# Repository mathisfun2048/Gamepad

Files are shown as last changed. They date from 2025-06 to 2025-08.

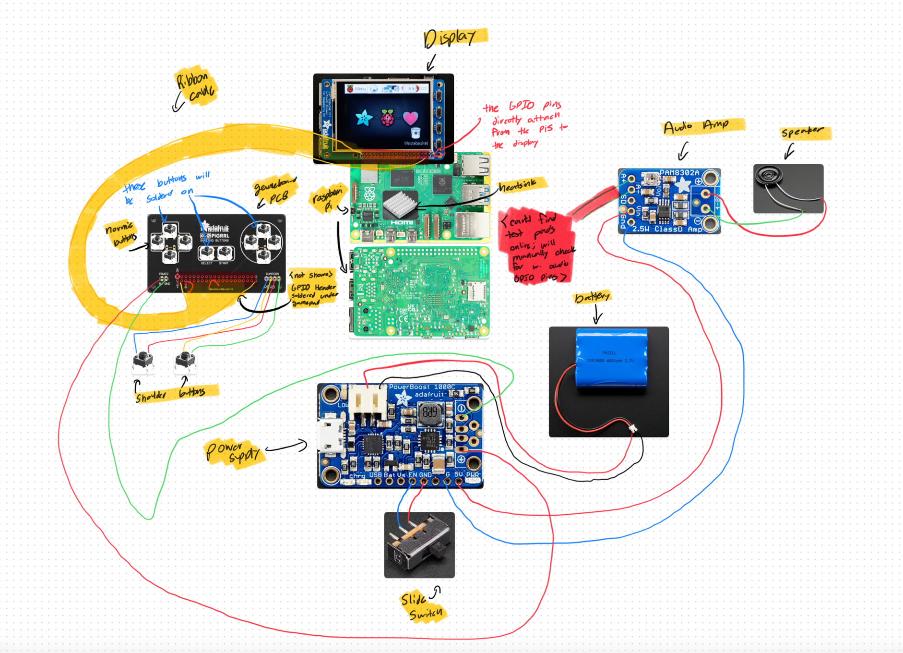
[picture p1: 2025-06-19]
Wiring/Screenshot 2025-06-19 at 6.52.05 AM.png

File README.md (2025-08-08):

# Gamepad


## Description and Exigence
Hallo! This is my second attempt at hardware design! This time, instead of focusing on a PCB, I wanted to investigate how multiple different parts can come together to create a product. The goal of this project is to create a functional gameboy-esq device that I can play games on! Initially this project was meant to fit inside of an altoids tin, but that was above my skill grade, so I downgraded to a slighly clunkier console. 

I have always enjoyed playing video games but never really considered how the hardware was created. So, this project hit 2 birds with 1 stone: I get a super cool gaming console to add to my collection and I get to learn about hardware >:) 
This project helped me get a glimse and greater appreciation of how hard hardware desgining and moreso planning. However, I picked up some cool skills which was really fun. 

A goal I had for this project specficially was to learn how to CAD using code, which I was able to do using a python script! I can't wait to see how it looks printed out irl. I have always been into coding and its been great seeing a way to directly merge my interest for talking with computers with creating something physical. 

Okay enough yap. If you want more stream of consciousness, look at my journal ;)

## PICTURES

### Schematic

Screenshot 2025-06-30 at 4 40 49 AM

Screenshot 2025-06-23 at 3 18 57 PM

### PCB 

Screenshot 2025-06-30 at 4 41 06 AM

Screenshot 2025-06-23 at 3 19 37 PM

### project as a whole

Everything Together

Top View

## Firmware
So tldr I don't know how to code games (yet!) so I will be utalizing RetroPi. It is not included in this repo because 1) github was being finicky about pushing it from my desktop folder and 2) its avalible online readilly 

## BOM

Here's everything you need if you want to build this too! (also includes sweat and tears... forgot to include that in the table)

Also, you might be wonderign why everything is either from Microcenter or Adafruit and not cheaper alternatives like AliExpress. The short answer is my parents won't allow me to purchase stuff from aliexpress. However, if my cost goes above the alloted $150 with future edits or anything, I will be more than happy to pay out of pocket. If this project gets downgraded to 4 points, I'd also be willing to pay out of pocket because this is honestly pretty cool and I want to see it in person. I never got a handheld video game console as a kid and I'm excited that I'll be able to make one now :)

| Item | Quantity | Cost | Source | Link |
| --- | --- | --- | --- | --- |
| Raspberry Pi Zero 2 | 1 | 14.99 | Microcenter | [Link](https://www.microcenter.com/product/643085/raspberry-pi-zero-2-w) |
| GPIO header | 1 | 5.99 | Microcenter | [Link](https://www.microcenter.com/product/480889/schmartboard-inc-schmartboard-inc-2-x-20-male-headers-qty-5) |
| 2.2" Display | 1 | 24.95 | Adafruit | [Link](https://www.adafruit.com/product/2315) |
| Custom PCB | 1 | $9 + shipping | JCL PCB | |
| PowerBoost 1000c | 1 | 19.99 | Microcenter | [Link](https://www.microcenter.com/product/474415/adafruit-industries-powerboost-1000-charger-rechargeable-5v-lipo-usb-boost-@-1a) |
| 2500 mAh Battery | 1 | 14.99 | Adafruit | [Link](https://www.microcenter.com/product/454401/adafruit-industries-lithium-ion-polymer-battery-37v-2500mah) |
| stacking header | 1 | 2.95 | Adafruit | [Link](https://www.adafruit.com/product/1979?srsltid=AfmBOoqbo1ndLmYMVLTt_bqD4Yhi48SgEFRf9jc0nGi86ePSABa_MOBi) |
| Slide Switch | 1 | 0.95 | Adafruit | [Link](https://www.adafruit.com/product/805) |
| 6mm Tactile Buttons | 10 | 9.99 | Microcenter | [Link](https://www.microcenter.com/product/632688/inland-6x6mm-micro-momentary-tactile-push-button-switches-assortment-kit-10-values-180-pcs) |
| #4-40 3/8" Machine Screws | 14 | 0.00 | Myself | n/a |
| #2-56 3/8" Machine Screws | 6 | 0.00 | Myself | n/a |
| **Total** |  | **~110** | |

## Closing Remarks On Planning

This has been such a fun thing to fall into this rabbithole where I could desing this. Without Highway (shoutout Hack Club!) I would never have learned this much about hardware in such a short time; I am very grateful for this opportunity. While I do have to part now, I can't wait to build it and enter in my final remarks after I get this to work!

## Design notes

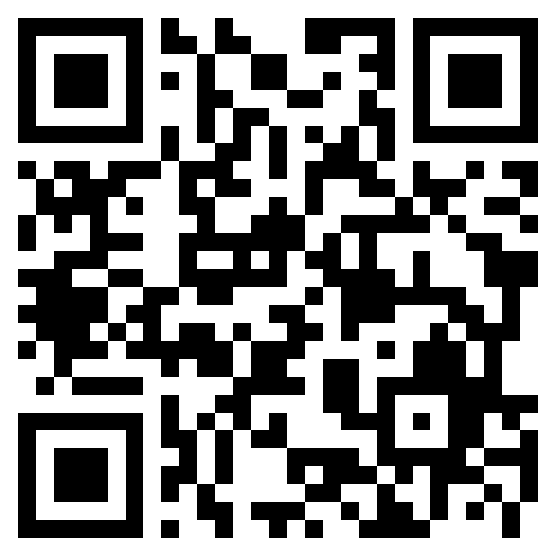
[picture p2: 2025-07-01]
Assets/Image.png

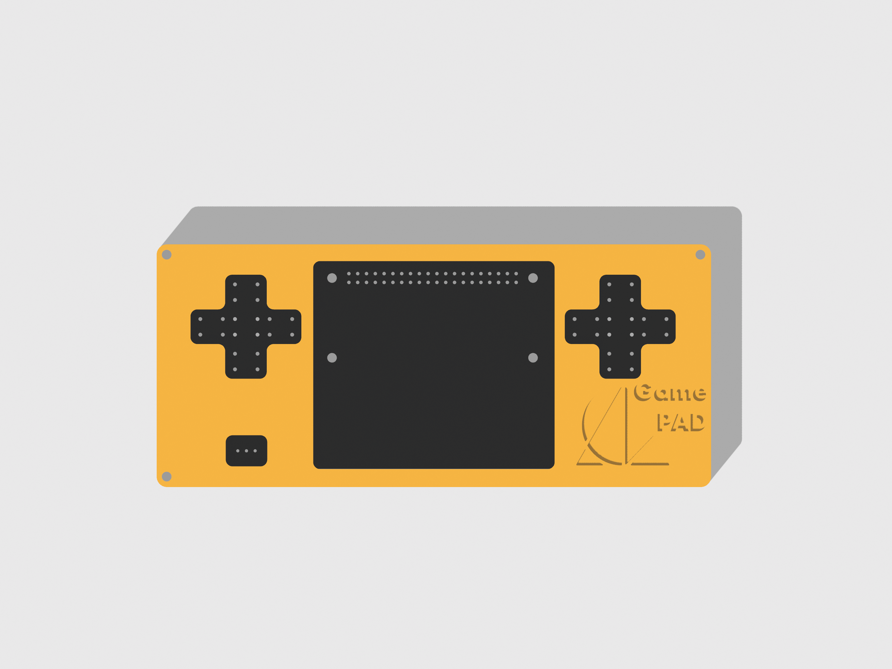
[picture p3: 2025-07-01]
Assets/Top View.png

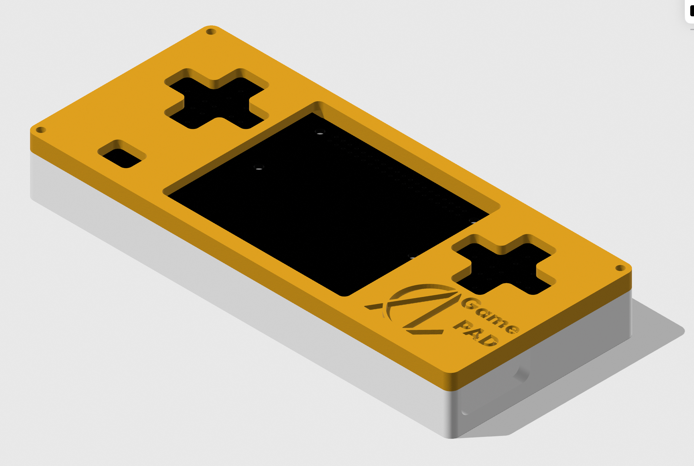
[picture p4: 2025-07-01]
Assets/Everything Together.jpeg

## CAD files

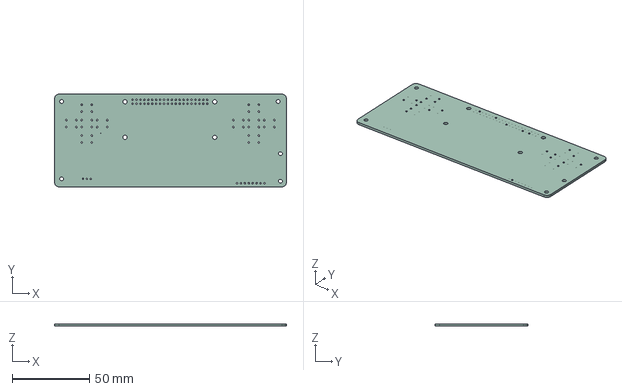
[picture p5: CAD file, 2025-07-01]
CAD/Gamepad_PCB.step
150.0 x 60.0 x 1.51 mm

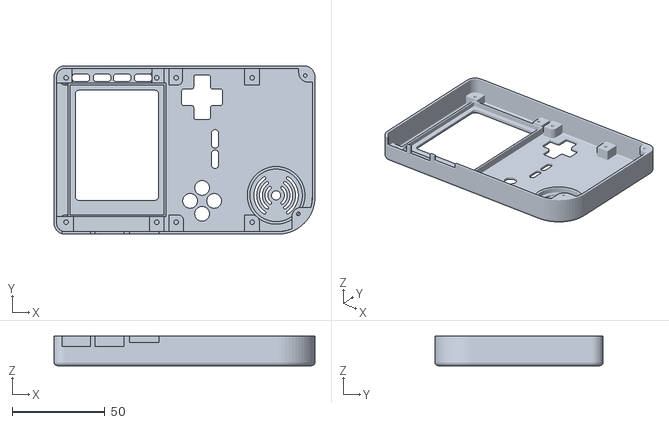
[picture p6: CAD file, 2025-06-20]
Production/top case for gamepad v2 copy.stl
141.0 x 91.0 x 16.0

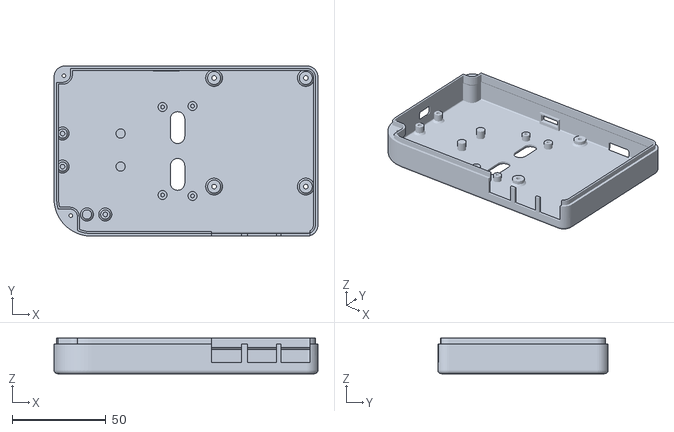
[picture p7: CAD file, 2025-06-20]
Production/bottom case for gamepad v4 copy.stl
141.0 x 91.0 x 19.0

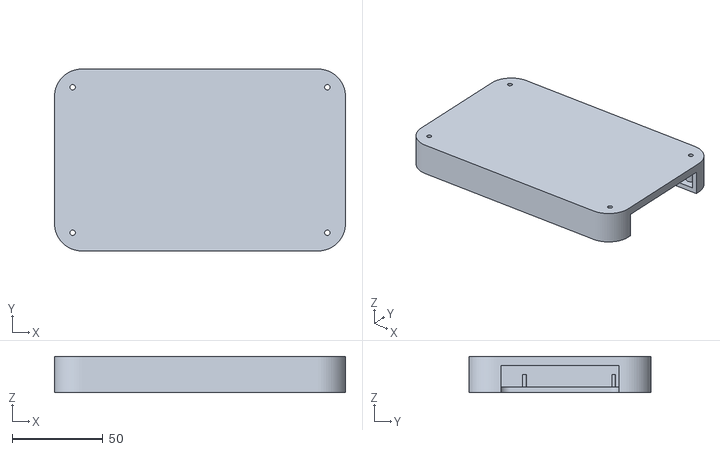
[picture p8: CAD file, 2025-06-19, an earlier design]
CAD/bottom case for gamepad v3.stl
160.0 x 100.0 x 20.0

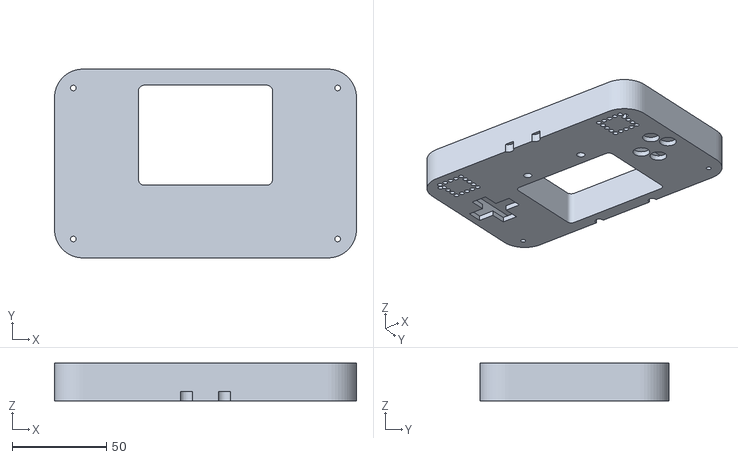
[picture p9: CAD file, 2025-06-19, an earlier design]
CAD/top case for gamepad v1.stl
160.0 x 100.0 x 20.0

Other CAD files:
CAD/bottom case for gamepad v4 STEP.step
CAD/top case for gamepad v2 STEP.step
archive from old design/bottom case for gamepad v4 STEP.step
archive from old design/top case for gamepad v2 STEP.step

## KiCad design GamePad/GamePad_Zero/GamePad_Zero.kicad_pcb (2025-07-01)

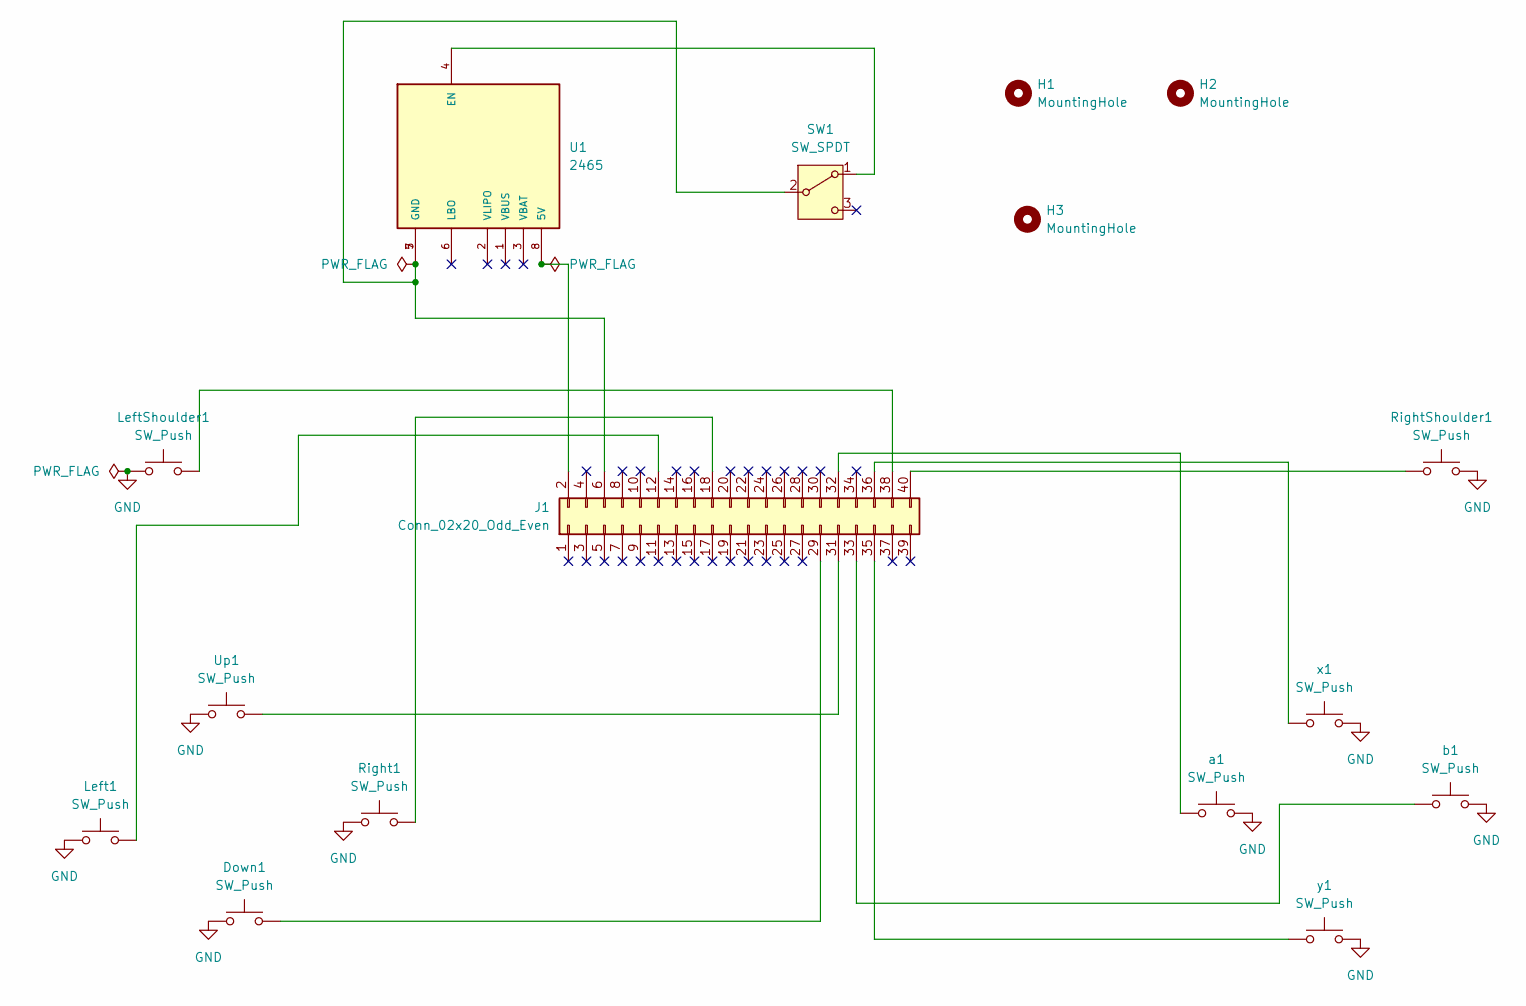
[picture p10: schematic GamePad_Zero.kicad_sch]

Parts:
Down1: SW_Push; SW_PUSH_6mm
H1, H2, H3: MountingHole; MountingHole_2.5mm
J1: Conn_02x20_Odd_Even; MODULE_SC1176
Left1: SW_Push; SW_PUSH_6mm
LeftShoulder1: SW_Push; SW_PUSH_6mm
Right1: SW_Push; SW_PUSH_6mm
RightShoulder1: SW_Push; SW_PUSH_6mm
SW1: SW_SPDT; SW_MINI-SPDT-SW
U1: 2465; MODULE_2465; PARTREV B
Up1: SW_Push; SW_PUSH_6mm
a1: SW_Push; SW_PUSH_6mm
b1: SW_Push; SW_PUSH_6mm
x1: SW_Push; SW_PUSH_6mm
y1: SW_Push; SW_PUSH_6mm

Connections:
GND: Down1.1, Left1.1, LeftShoulder1.1, Right1.1, RightShoulder1.2, Up1.1, a1.2, b1.2, x1.2, y1.2
unnamed: J1.2, U1.8 (5V)
unnamed: J1.6, SW1.2 (B), U1.5 (GND), U1.7 (GND)
unnamed: J1.12, Left1.2
unnamed: J1.18, Right1.2
unnamed: Down1.2, J1.29
unnamed: J1.31, Up1.2
unnamed: J1.32, a1.1
unnamed: J1.33, b1.1
unnamed: J1.35, y1.1
unnamed: J1.36, x1.1
unnamed: J1.38, LeftShoulder1.2
unnamed: J1.40, RightShoulder1.1
unnamed: SW1.1 (A), U1.4 (EN)

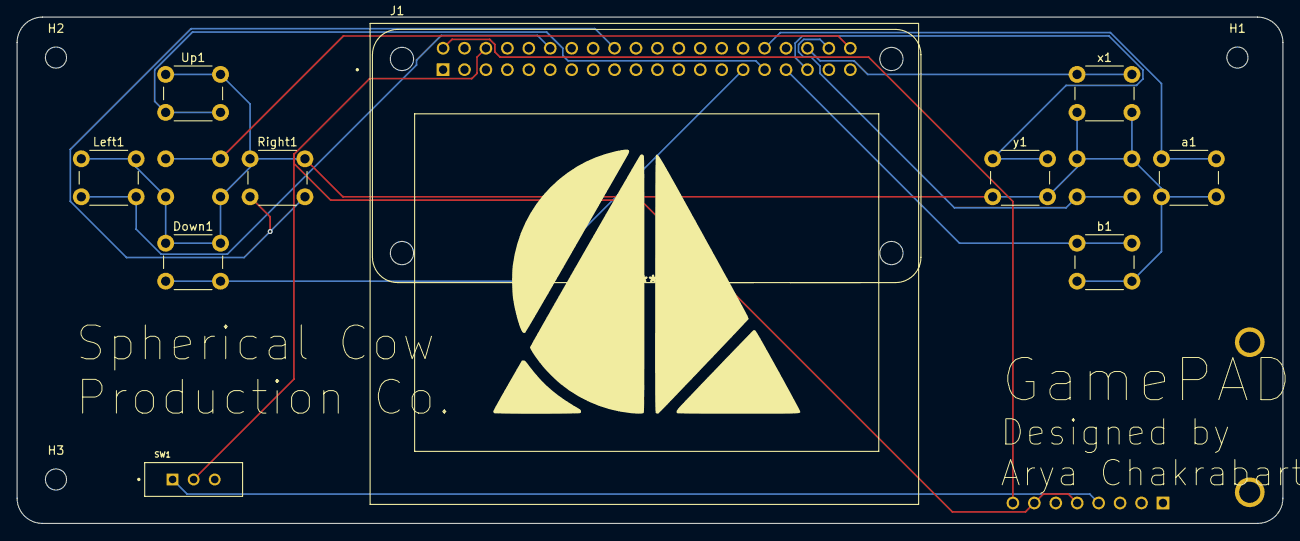
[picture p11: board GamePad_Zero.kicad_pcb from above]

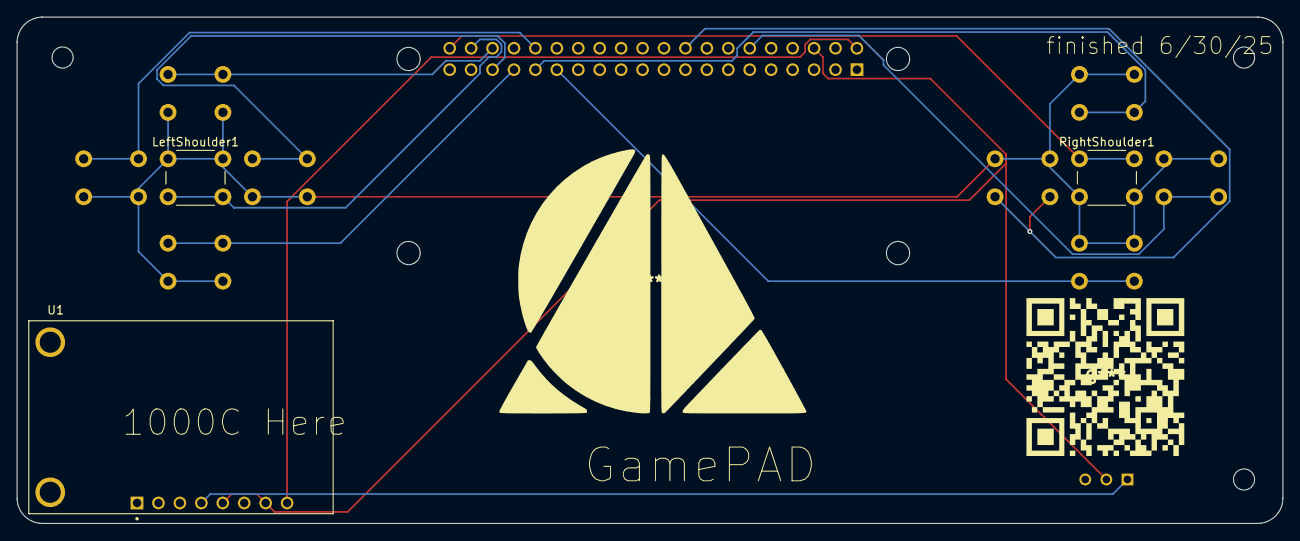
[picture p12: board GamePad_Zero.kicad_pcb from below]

Board: 2 copper layers, 150.0 x 60.0 mm, 16 parts (3 on the bottom side), 14 nets.

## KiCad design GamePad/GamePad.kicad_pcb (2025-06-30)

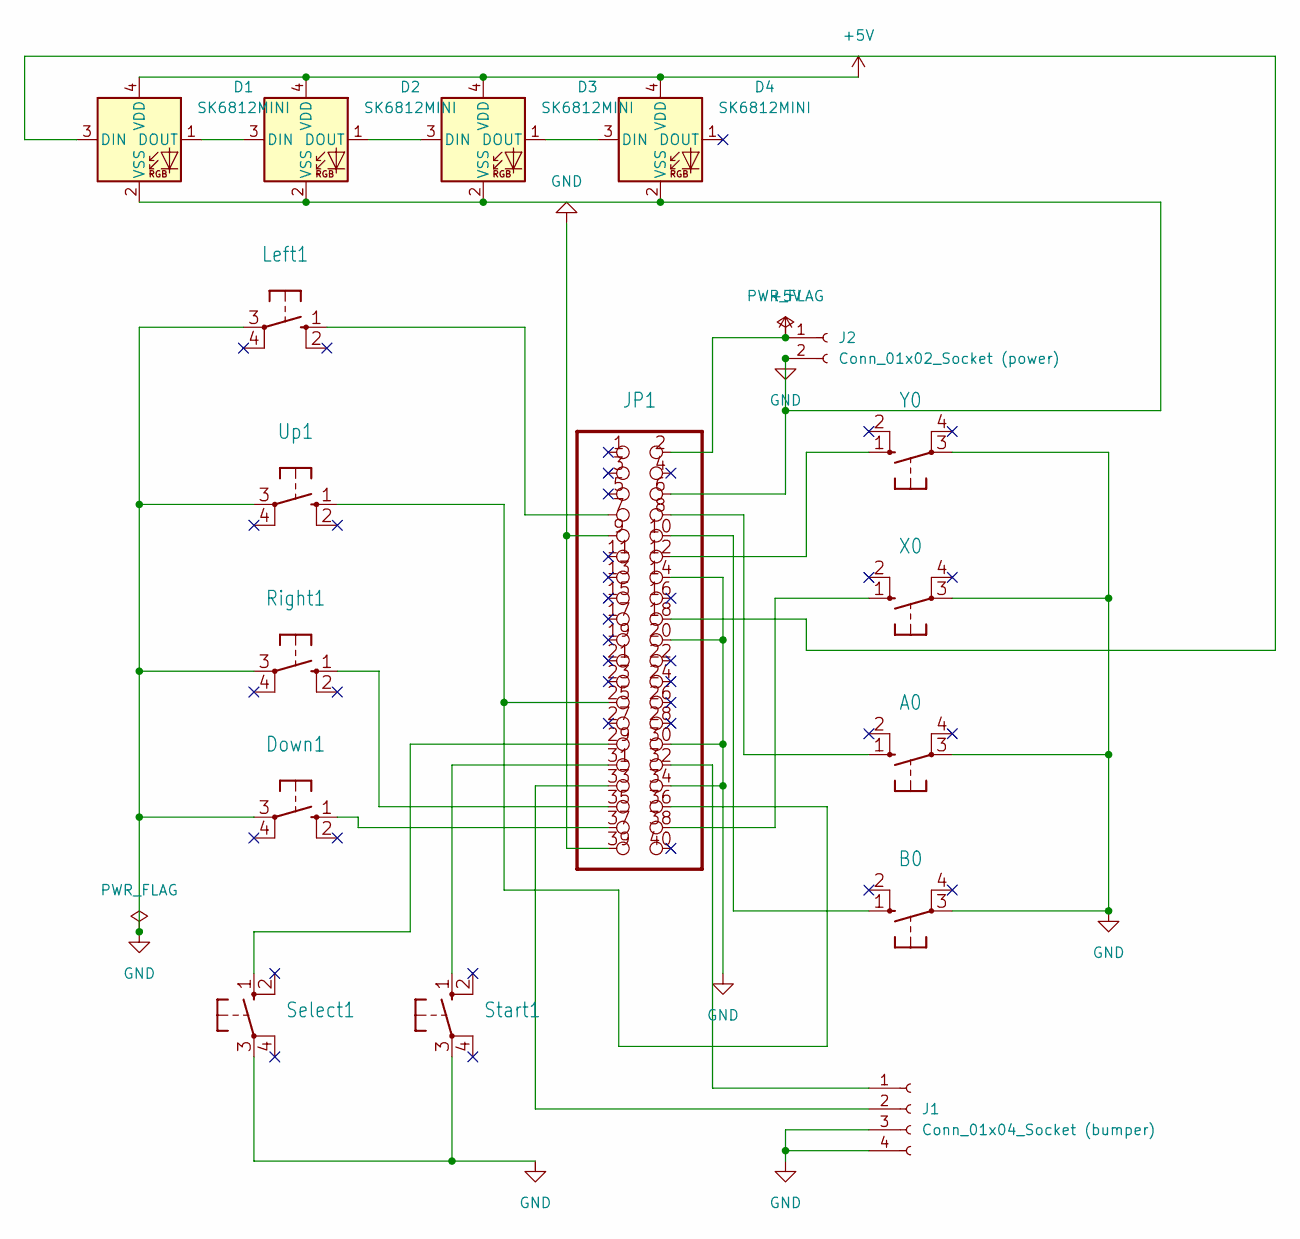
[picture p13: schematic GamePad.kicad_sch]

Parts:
A0: B3F-10XX
B0: B3F-10XX
D1, D2, D3, D4: SK6812MINI; LED_SK6812MINI_PLCC4_3.5x3.5mm_P1.75mm
Down1: B3F-10XX
J1: Conn_01x04_Socket (bumper); 1X04
J2: Conn_01x02_Socket (power); 1X02
JP1: 2X20
Left1: B3F-10XX
Right1: B3F-10XX
Select1: B3F-10XX
Start1: B3F-10XX
Up1: B3F-10XX
X0: B3F-10XX
Y0: B3F-10XX

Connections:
+5V: D1.4 (VDD), D2.4 (VDD), D3.4 (VDD), D4.4 (VDD), J2.1, JP1.2
GND: A0.3, B0.3, D1.2 (VSS), D2.2 (VSS), D3.2 (VSS), D4.2 (VSS), Down1.3, J1.3, J1.4, J2.2, JP1.6, JP1.9, JP1.14, JP1.20, JP1.30, JP1.34, JP1.39, Left1.3, Right1.3, Select1.3, Start1.3, Up1.3, X0.3, Y0.3
unnamed: A0.1 (S), JP1.8
unnamed: B0.1 (S), JP1.10
unnamed: D1.3 (DIN), JP1.18
unnamed: D1.1 (DOUT), D2.3 (DIN)
unnamed: D2.1 (DOUT), D3.3 (DIN)
unnamed: D3.1 (DOUT), D4.3 (DIN)
unnamed: Down1.1 (S), JP1.37
unnamed: J1.1, JP1.32
unnamed: J1.2, JP1.33
unnamed: JP1.7, Left1.1 (S)
unnamed: JP1.35, Right1.1 (S)
unnamed: JP1.29, Select1.1 (S)
unnamed: JP1.31, Start1.1 (S)
unnamed: JP1.25, JP1.36, Up1.1 (S)
unnamed: JP1.38, X0.1 (S)
unnamed: JP1.12, Y0.1 (S)

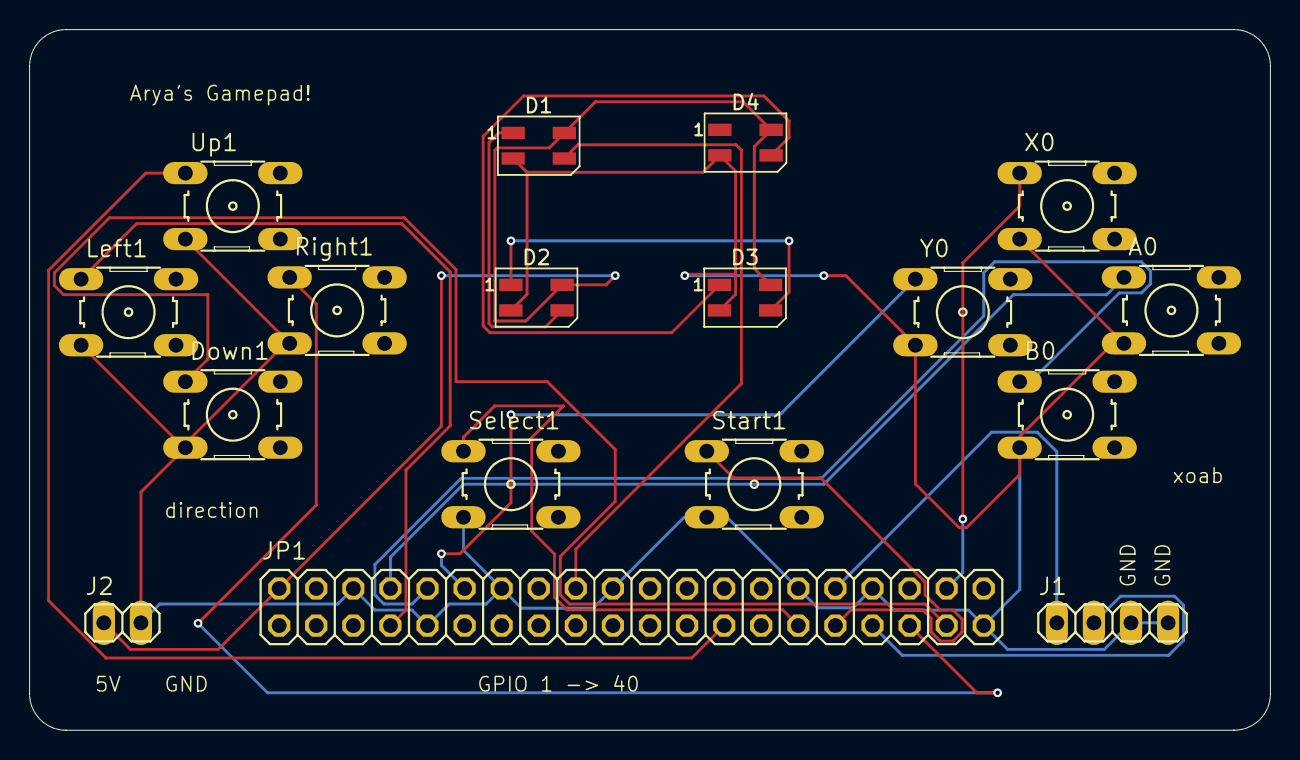
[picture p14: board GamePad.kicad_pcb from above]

Board: 2 copper layers, 85.0 x 48.0 mm, 17 parts (0 on the bottom side), 18 nets.

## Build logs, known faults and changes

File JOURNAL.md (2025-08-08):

---
title: "Gamepad"
author: "Arya Chakrabarti (Arya)"
description: "This project is to create a retro gamepad!"
created at: "06-18-2025"
---

total time spent prepping: 30 hours (in ~~one~~ two go(s)! Undiagnosed ADHD!) (will increase expoentnially once I have it in front of me and I find ways to improve it)

# June 8th
## 10AM -> 6 PM : planning (8 hours)
This is my first custom hardwre project, so I've been a tad nervous (thats why this took so long!). I spent this time researching what making a game console entails and sourcing possible parts. I have learned that this is more than just plug and play (haha) and in order to make a clean design I found I need to make some custom PCBs to wire everything up without clunky wires sticking out. I found multiple different processing chips, but settled on a raspberry pi because of how prevelent it is--I am new to this and am glad I will find support if I use this chip. In addition, I sketched out a rough drawing on what I want my gamepad to look like: I want a nintendo 3ds like setup with the screen on the top lid of the altoids tin and all the guts of the system on the bottom portion. For buttons, I want a D pad, A and B, and 2 system buttons. 

Screenshot 2025-06-19 at 7 49 12 AM

### Projected BOM

#### Core Computing and Storage
- Raspberry Pi Zero 2W
- SanDisk Ultra 64GB microSD
- GPIO Header (40-pin)

#### Display
- 2.8" TFT LCD Display
- Ribbon Cable (10-wire)

#### Power
- Li-Po 3.7 V 1200 mAh
- PowerBoost 1000C power supply
- Power Switch
- USB-C Breakout

#### Controls
- Tactile Switches (8x)
- D-Pad Cap
- Button Caps (4x)
- MCP23017 I/O Expander

#### Audio
- MAX98357A I2S Amp
- Mini Speaker

#### PCBs
- Main PCB
- Display Lid PCB
- Resistors (Assorted)
- Capacitors (Assorted)
- JST Connectors
- Pin Headers
- Level Shifters (4x)

#### Assembly
- Altoids tin
- Piano Hinge
- Neodymium Magnets (2x)
- Heat-Set Inserts (16x)
- Machine Screws
- Ribbon Cable
- Cable Management
- Double Sided Tape
- Kapton Tape
- Silicone Wire Kit
- Heat Shrink Kit

#### 3D Printed Parts
- Top Lid Screen Bezel 
- Bottom Case Component Tray 
- Bottom Case Button Plate 
- Cable Management Guide

### Physical Design

#### Top Case
- 2.8" LCD screen mounted in 3D-printed bezel/frame
- Screen protection via recessed mounting
- Hinge mechanism for smooth 180° opening
- Magnetic closure for secure shut
- Cable routing through hinge area

#### Bottom Case

##### Layer 1 (Bottom): Core components
- Raspberry Pi Zero 2W
- 1200mAh Li-Po battery
- PowerBoost 1000C charging circuit
- MAX98357A audio amplifier

##### Layer 2 (Middle): Main PCB with controls
- 8-button tactile switch layout
- MCP23017 I/O expander
- Power switch and charging port
- Speaker  

##### Layer 3 (Top): 3D-printed button interface
- Button caps and D-pad
- Clean, comfortable gaming surface
- Logo/labeling area

# June 9th 
## 12AM -> 1AM (1 hour)

So I realized I am way over my head and with my current skill level this project is impossible! So I am going to try a easier version of this project because I still want to make a cool retro game device. Instead of an cramped altoid tin a altoid tin and a pi zero, I think I will move on to a full on raspberry pi. I will update this with an update BOM and design once I'm done researching. Hopefully this takes less time :D

## 1AM -> 2AM (1 hour)

Great news! I found a tutorial from a couple years ago about how to do exactly this: a beginer friendly raspberry pi retro gaming console tutorial. A problem is that this tutorial is a tad old, so I have to modernize it. This includes modernizing the computer PCB (from a raspberry pi 1 to a raspberry pi 5) and followingly change the power and thermal architechture. For this, I am going to include a signficiantly larger battery, a more powerful power supply, and incororpate heat sinks. This is really cool becasue now I can learn more about a different part of design than what I learned when I made my macropad: in that project, I focused enterily on the pcb basics itself while now in this project, I can consider the product more holistically. I'm excited!

### Updated BOM

#### electronics
- Raspberry Pi 5
- 2.8" PiTFT Display
- PiGRRL Gamepad PCB
- PowerBoost 1000c
- 6600 mAh battery
- PAM8302 2.5W Audio Amp
- Mini metal speaker
- 40 pin GPIO ribbon cable
- slide switch
- 10x 6mm tactile buttons
- 2x 12mm tactile buttons
- 2x20 pin IDC box header
- heat sink kit

#### hardware
- 14x #4-40 3/8 machine screws
- 6x #2-56 3/8 machine screws

## 2AM -> 4AM (2 hours)

Time to make the circuit diagram! This is going to be exciting. 

Here it is!:


Okay quick update though: I couldn't find online which were teh test pads for audio, which I need to know so I can solder the amp onto the raspberry pi. Because of this, I will have to manually check the testpads agaisnt gpio pins 12, 35, and 40 to see which ones are audio related. Thankfully this issue is not too big. One thing I did learn through making this wiring diagram is that even though this project is significantly more simplistic than my previous altoid tin design, it is still super challenging. I am glad I am learning though! 

## 4AM -> 7AM (3 Hours)
Time to make the CAD file for the case! Wish me luck...

mini update at 5AM 
I tried using scripts to automate it because I want a simple block-y case, but that did not go well! But this is fun so I think I'll continue
Screenshot 2025-06-19 at 4 58 39 AM

Will update when I fix this!

Update: 5:30 AM: I GOT THE BOTTOM CASE TO WORK!!!!!
Screenshot 2025-06-19 at 6 24 46 AM

Update: 6:30AM I think I am done with the case design! Doing it through code was a really fun exerciese and I'm glad I've been able to learn how to use python to CAD!

Bottom case:
Screenshot 2025-06-19 at 6 43 27 AM

Top Case:
Screenshot 2025-06-19 at 6 44 06 AM

## 7AM -> 9AM (2 hours)
In this hour I polished everything up for final review! Hopefully you llike what I made so far!! I want to affirm, though, that this was my first time really sourcing parts myself and buildign something so I expect myself to course correct after I have everythign in front of me--I am a very tactile perosn and I love fiddling arround :D

WHY DOES IT TAKE THIS LONG TO UPLOAD A STUPID DESKTOP FOLDER TO GITHUB AHGHGHGDHAKLGHASDLF AKSLD FJA;FA 
i digress...

# June 20

## 6AM -> 3PM (9 hours)

I was going over my initial PCB design and found I have need some more holes TO THE SIDE OF TEH DISPLAY

This means my horizontal design will no longer work and I need a vertical deign. 

I found a sample online gameboy knockoff that I realy liked, so I spent the last 9 hours emulating that! Its been fun learning more about CAD since this is my second project. As a homage to the first itteration, those files are still in the CAD and production folders, but for practical purpouses I will use the newer versions. I feel takign time to emulate a prof. design taught me a lot of things that I would not have learned by simply making a "box" --for one I leanred how to make screw holes which are not just straight through!!! Very cool indeed. One thing that mildly irked me is how stupidly clunky it looks now... maybe ill try to adapt this to a pi zero in the future.... stay tuned >:)

Screenshot 2025-06-20 at 3 31 39 PM

Screenshot 2025-06-20 at 3 31 56 PM

super cool sketch:



# June 21

## 2PM -> 3PM (1 hour)
switched pi5 to pi zero 2w to reduce cost!

Here is the updated wiring diagram!


# June 23
## 12:30PM -> 3:30PM (3 hours)

Spent this time makign a custom PCB! It was super fun learning more about what each gpio pin on a raspberry pi is connected to and refining my wiring abilities. I saw this took significantly less time than the hackpad, which I'm proud of :)

### Schematic
Screenshot 2025-06-23 at 3 18 57 PM

### PCB 
Screenshot 2025-06-23 at 3 19 37 PM

### updated layout


# June 29

## 8PM -> 9PM (1 hour)

I was going to order my PCB but thought the encloser looked not the best, so I wanted to refine the design. Using the skills I learned from my PaperCAM and PassPAD projects, I am making a new PCB that utalizes pass-through GPIO pins to best utalize the form-factor of the raspberry pi zero 2 w. Right now, I'm envisioning this:

<rpi> -> < pcb with buttons and stuff> -> <display>

Here's my updated schematic reflecting this. So excited to continue this project!

Screenshot 2025-06-30 at 2 34 40 AM

## 2AM -> 5AM (3 Hours)

So I had a lot of growth in these 2 hours! I finally figured out how to position itmes per the grid (all I had to do was press e...). So now, instead of zooming in a ton and movign items pixel by pixel, I just did some math. 

The main problem was selecting where the buttons were going to be attached to the PCB. I centered them in teh space between the display and the edge of the device (oh yeah the dimensions for the PCB should be 150x60). I settled on a 10mm spacing between the centers of teh buttons, allowing them to be well spaced for gaming. The shoulder burttons are going to be located on the middle of the d-pads on both sides. 

Screenshot 2025-06-30 at 4 24 20 AM

Screenshot 2025-06-30 at 4 36 54 AM

## 3PM -> 7PM (4 hours)

finished the CAD case! 

All done (until my parts arrive!)

Top View

Everything Together

I really really like how this turned out--it looks so cool! Just 1 month ago I had no clue what hardware was, and seeing that I've been able to ship a project is really satisfying. 

# August 1 6AM -> 6PM (12 hours)

I finished building it! Here's some snapshots during my build process:

some things I learned during this:
1. software is really fricking hard. thank you retropi for making this open source
2. double check pcbs before sending them to print... the ground for the buttons were not connected to system ground so I needed to solder a wire for that connection so it works











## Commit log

2025-06-19 Initial clean commit
    [BOM for Gamepad - Sheet1.csv, bottom case for gamepad v3.stl, top case for gamepad v1.stl]
2025-06-20 new cad files!
    [bottom case for gamepad v4 copy.stl, bottom case for gamepad v4.stl, top case for gamepad v2 copy.stl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]
2025-06-20 deleted old cad files
    [bottom case for gamepad v3.stl, top case for gamepad v1.stl]
2025-06-20 added STEP files
    [bottom case for gamepad v4 STEP.step, top case for gamepad v2 STEP.step]
2025-06-20 Update top case for gamepad v2 STEP.step
    [top case for gamepad v2 STEP.step]
2025-06-20 Update bottom case for gamepad v4 STEP.step
    [bottom case for gamepad v4 STEP.step]
2025-06-21 Update BOM for Gamepad - Sheet1.csv
    [BOM for Gamepad - Sheet1.csv]
2025-06-22 some misc. files added
    [BOM for Gamepad - Sheet1.csv, bottom case for gamepad v3.stl, bottom case for gamepad v4 STEP.step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]
2025-06-22 added some misc files
    [BOM for Gamepad - Sheet1.csv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]
2025-06-23 added custom PCB
    [GamePad.kicad_pcb, GamePad.kicad_sch]
2025-06-30 finished new PCB
    [GamePad.kicad_pcb, GamePad_Zero.kicad_pcb, GamePad_Zero.kicad_sch]
2025-07-01 finishing touches
    [GamePad_Zero-B_Cu.gbr, GamePad_Zero-B_Mask.gbr, GamePad_Zero-B_Paste.gbr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]
